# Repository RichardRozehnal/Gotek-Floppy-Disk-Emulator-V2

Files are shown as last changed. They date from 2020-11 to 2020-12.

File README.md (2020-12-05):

# Gotek Floppy Disk Emulator V2

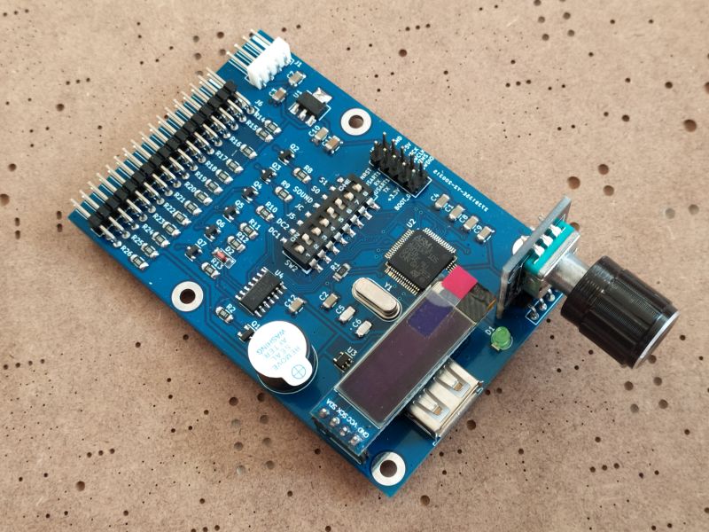
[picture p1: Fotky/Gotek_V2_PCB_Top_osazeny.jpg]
Gotek Floppy Disk Emulator V2


Emulátor disketové mechaniky starých počítačů a různých zařízení. Software se do počítače nahrává z obrazu originálního disku (např. ADF pro Amigu), který je uložen na USB flash disku. Tato verze hardwaru využívá firmware [FlashFloppy](https://github.com/keirf/FlashFloppy/wiki), který přidává spoustu nových funkcí a vylepšení oproti standardnímu Goteku. Na uvedém odkazu tvůrce, najdete detailní popisy všech funkcí a nastavení a také nejnovější firmware.

## Seznam součástek

| **Ref** | **Qnty** | **Value** | **Cmp name** |
| --- | :---: | --- | --- |
| BZ1, | 1 | 5V Active Buzzer 12mm | Buzzer |
| C1, C2, C4, C7, C8, C9, C10, C12, | 8 | 100nF | C |
| C3, C11, | 2 | 10uF | C |
| C5, C6, | 2 | 22pF | C |
| C13, | 1 | 4.7uF/16V | CP |
| D1, | 1 | LED Green | LED |
| D2, | 1 | 1N4148 | D |
| J1, | 1 | Power Connector | Conn\_01x04 |
| J2, | 1 | OLED Display 0.91" Module | OLED\_Display\_0.91"\_Module |
| J3, | 1 | USB\_A | USB\_A |
| J5, | 1 | Programming Connector | Conn\_02x05\_Odd\_Even |
| J6, | 1 | Floppy Data Connector | Conn\_02x17\_Odd\_Even |
| Q1, | 1 | MMBT2222 | Q\_NPN\_BEC |
| Q2, Q3, Q4, Q5, Q6, Q7, | 6 | BSS123 | BSS123 |
| R1, | 1 | 4K7 | R |
| R2, R3, R7, R8, R9, R10, R11, R12, R13, R14, R15, R16, R17, R18, R19, R20, R21, R22, R23, R24, R25, R26, | 22 | 1K | R |
| R4, R27 | 2 | 10K | R |
| R5, R6, | 2 | 22R | R |
| SW1, | 1 | KY040 Rotary Encoder Module | KY040\_Rotary\_Encoder\_Module |
| SW2, | 1 | DIP Switch | DIP\_Switch |
| U1, | 1 | AMS1117-3.3 | AMS1117-3.3 |
| U2, | 1 | STM32F105RBTx | STM32F105RBTx |
| U3, | 1 | STMPS2141 | STMPS2141 |
| U4, | 1 | 74HCT04 | 74HCT04 |
| Y1, | 1 | 8MHz | Crystal |

## Oživení

### Programování mikrokontroléru pomocí ST-Link V2

1. stáhněte si a nainstalujte flashovací program STM32-ST-Link Utility na webu [st.com](https://www.st.com/en/development-tools/stsw-link004.html).
2. propojte ST-Link V2 a Gotek V2 vývody SWCLK, SWDIO, GND a +3.3V
3. připojte ST-Link V2 k PC a spusťte flashovací program
4. připojte se na MCU přes menu Target/Connect
5. přes menu File/Open File vyberte soubor FF_Gotek-v3.20.hex (nebo jiný, který chcete nahrát do MCU)
6. spusťte flashování přes menu Target/Program & Verify a Start

### Nastavení DIP přepínače SW2

Pro Amigu, Atari ST a další počítače je nastavení:

| **sig** | **zap/vyp** | **funkce** |
| :-----: | :---: | --- |
| DC1 | OFF | |
| DC2 | ON | |
| J5 | OFF | |
| JC | OFF | |
| JB | ON | zapnutí/vypnutí emulace zvuku mechaniky |
| S0 | ON | |
| S1 | OFF | |

### Příprava USB flash disku a základní operace

1. USB flash disk naformátujte na FAT32 a nahrajte na něj obrazy disků, které budete chtít spouštět, např. ADF pro Amigu
2. připojte Gotek V2 s vloženým USB flash diskem k Amize (místo interního floppy disku), napájecí konektor je dobré před zapojením změřit, abyste do Goteku V2 nepustili 12V místo 5V, kvůli obrácení konektoru!
3. zapněte Amigu, na displeji se zobrazí první z podporovaných souborů, které jste nahráli a rotačním enkodérem mezi nima vybíráte
4. když najedete na soubor a počkáte 2s, tak se automaticky spustí (vloží do floppy mechaniky). Toto je možné v nastavení změnit, aby se automaticky nespouštěl. Potom bude pro vložení do mechaniky nutné stisknout rotační enkodér.
5. pokud chcete změnit orientaci posuvu v souborech (otáčení enkodéru doprava/doleva posouvat soubory nahoru/dolů), je to možné změnit v nastavení.
6. pokud se výběr souborů posune o jednu položku až při dvou nebo čtyřech krocích otočení enkodérem, je možné toto také upravit v nastavení

### Nastavení firmware

1. Gotek V2 funguje s defaultním nastavením i bez konfiguračního souboru
2. pokud však chcete určitou konfiguci změnit, vytvořte na USB flash disku adresář FF a do něj nahrajte konfigurační soubor FF.CFG
3. zrušení automatického spouštění souboru: autoselect-file-secs = 0
4. zrušení automatického vybrání adresáře: autoselect-folder-secs = 0
5. změna orientace posuvu v souborech: rotary = reverse
6. změna kroků enkodéru: rotary = half
7. je možné vybrat i více nastavení najednou, např.: rotary = reverse,half

## Další fotky (vzorky, úprava na BOT straně již není potřeba)

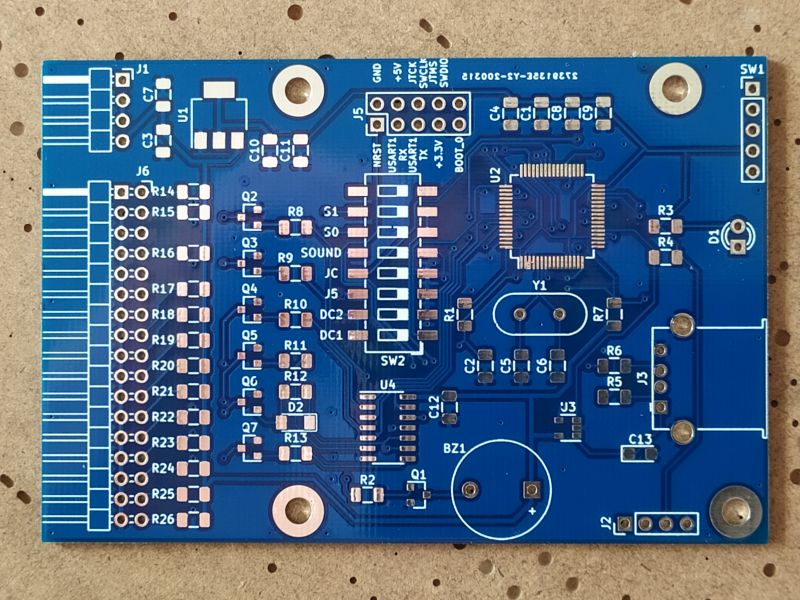
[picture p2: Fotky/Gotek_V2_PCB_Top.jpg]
Gotek_V2_PCB_Top

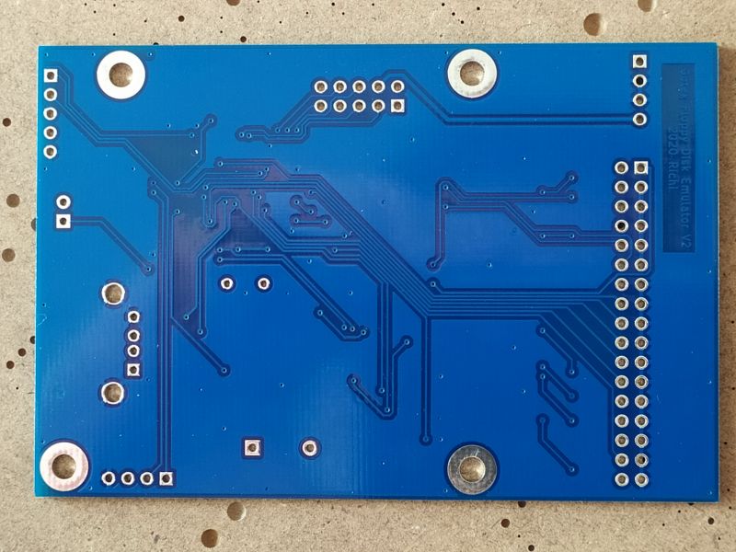
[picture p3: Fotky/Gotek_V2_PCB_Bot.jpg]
Gotek_V2_PCB_Bot

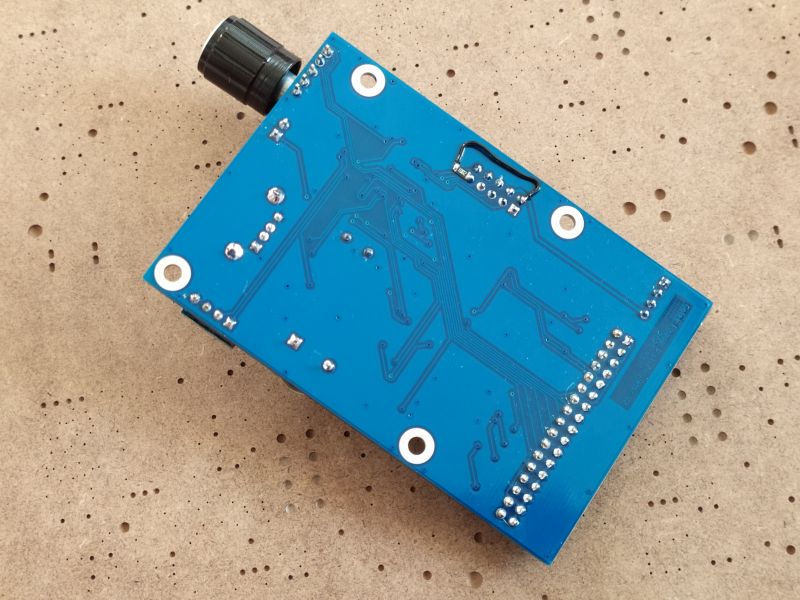
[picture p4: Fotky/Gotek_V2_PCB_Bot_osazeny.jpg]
Gotek_V2_PCB_Bot_osazeny


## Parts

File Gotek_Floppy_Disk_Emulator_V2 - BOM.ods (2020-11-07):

Gotek Floppy Disk Emulator V2 – BOM
Ref | Qnty | Value | Cmp name | Footprint
BZ1, | 1 | 5V Active Buzzer 12mm | Buzzer | Buzzer_12x9.5RM7.6
C1, C2, C4, C7, C8, C9, C10, C12, | 8 | 100nF | C | C_1206_3216Metric
C3, C11, | 2 | 10uF | C | C_1206_3216Metric
C5, C6, | 2 | 22pF | C | C_1206_3216Metric
C13, | 1 | 4.7uF/16V | CP | CP_EIA-3216-18_Kemet-A
D1, | 1 | LED Green | LED | LED_D3.0mm
D2, | 1 | 1N4148 | D | D_MiniMELF
J1, | 1 | Power Connector | Conn_01x04 | PinHeader_1x04_P2.54mm_Horizontal
J2, | 1 | OLED Display 0.91" Module | OLED_Display_0.91"_Module | OLED_Display_0.91_Module
J3, | 1 | USB_A | USB_A | USB_A_Stewart_SS-52100-001_Horizontal
J5, | 1 | Programming Connector | Conn_02x05_Odd_Even | PinHeader_2x05_P2.54mm_Vertical
J6, | 1 | Floppy Data Connector | Conn_02x17_Odd_Even | PinHeader_2x17_P2.54mm_Horizontal
Q1, | 1 | MMBT2222 | Q_NPN_BEC | SOT-23
Q2, Q3, Q4, Q5, Q6, Q7, | 6 | BSS123 | BSS123 | SOT-23
R1, | 1 | 4K7 | R | R_1206_3216Metric
R2, R3, R7, R8, R9, R10, R11, R12, R13, R14, R15, R16, R17, R18, R19, R20, R21, R22, R23, R24, R25, R26, | 22 | 1K | R | R_1206_3216Metric
R4, R27 | 2 | 10K | R | R_1206_3216Metric
R5, R6, | 2 | 22R | R | R_1206_3216Metric
SW1, | 1 | KY040 Rotary Encoder Module | KY040_Rotary_Encoder_Module | PinHeader_1x05_P2.54mm_Vertical
SW2, | 1 | DIP Switch | DIP_Switch | SW_DIP_SPSTx08_Slide_6.7x21.88mm_W8.61mm_P2.54mm_LowProfile
U1, | 1 | AMS1117-3.3 | AMS1117-3.3 | SOT-223-3_TabPin2
U2, | 1 | STM32F105RBTx | STM32F105RBTx | LQFP-64_10x10mm_P0.5mm
U3, | 1 | STMPS2141 | STMPS2141 | SOT-23-5
U4, | 1 | 74HCT04 | 74HCT04 | SOIC-14_3.9x8.7mm_P1.27mm
Y1, | 1 | 8MHz | Crystal | Crystal_HC49-4H_Vertical

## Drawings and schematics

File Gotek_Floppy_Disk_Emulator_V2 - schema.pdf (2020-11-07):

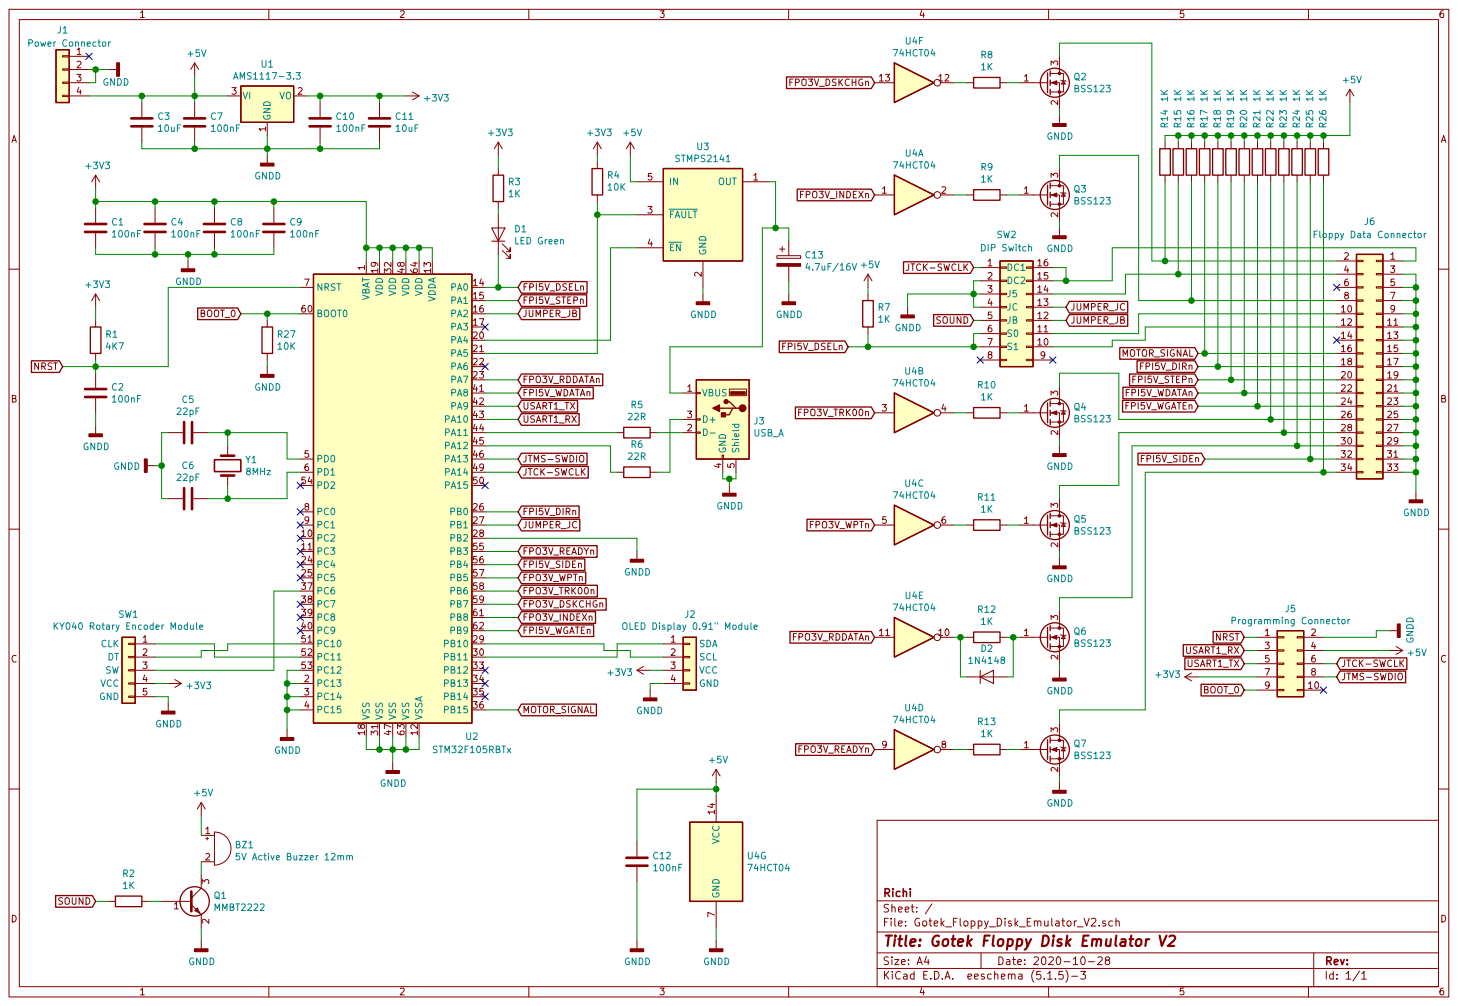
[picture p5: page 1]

1 PC2 10 PC3 11 VSSA 12 VDDA 13 PA0 14 PA1 15 PA2 16 PA3 17 VSS 18 VDD 19 PC13 2 PA4 20 PA5 21 PA6 22 PA7 23 PC4 24 PC5 25 PB0 26 PB1 27 PB2 28 PB10 29 PC14 3 PB11 30 VSS 31 VDD 32 PB12 33 PB13 34 PB14 35 PB15 36 PC6 37 PC7 38 PC8 39 PC15 4 PC9 40 PA8 41 PA9 42 PA10 43 PA11 44 PA12 45 PA13 46 VSS 47 VDD 48 PA14 49 PD0 5 PA15 50 PC10 51 PC11 52 PC12 53 PD2 54 PB3 55 PB4 56 PB5 57 PB6 58 PB7 59 PD1 6 BOOT0 60 PB8 61 PB9 62 VSS 63 VDD 64 NRST 7 PC0 8 PC1 9 U2 STM32F105RBTx GNDD
+3V3 GNDD GNDD

10 | | 9
12 | | 11
14 | | 13

18 | 17
20 | 19
22 | 21
24 | 23
26 | 25
28 | 27
30 | 29

Id: 1/1 Title: Gotek Floppy Disk Emulator V2

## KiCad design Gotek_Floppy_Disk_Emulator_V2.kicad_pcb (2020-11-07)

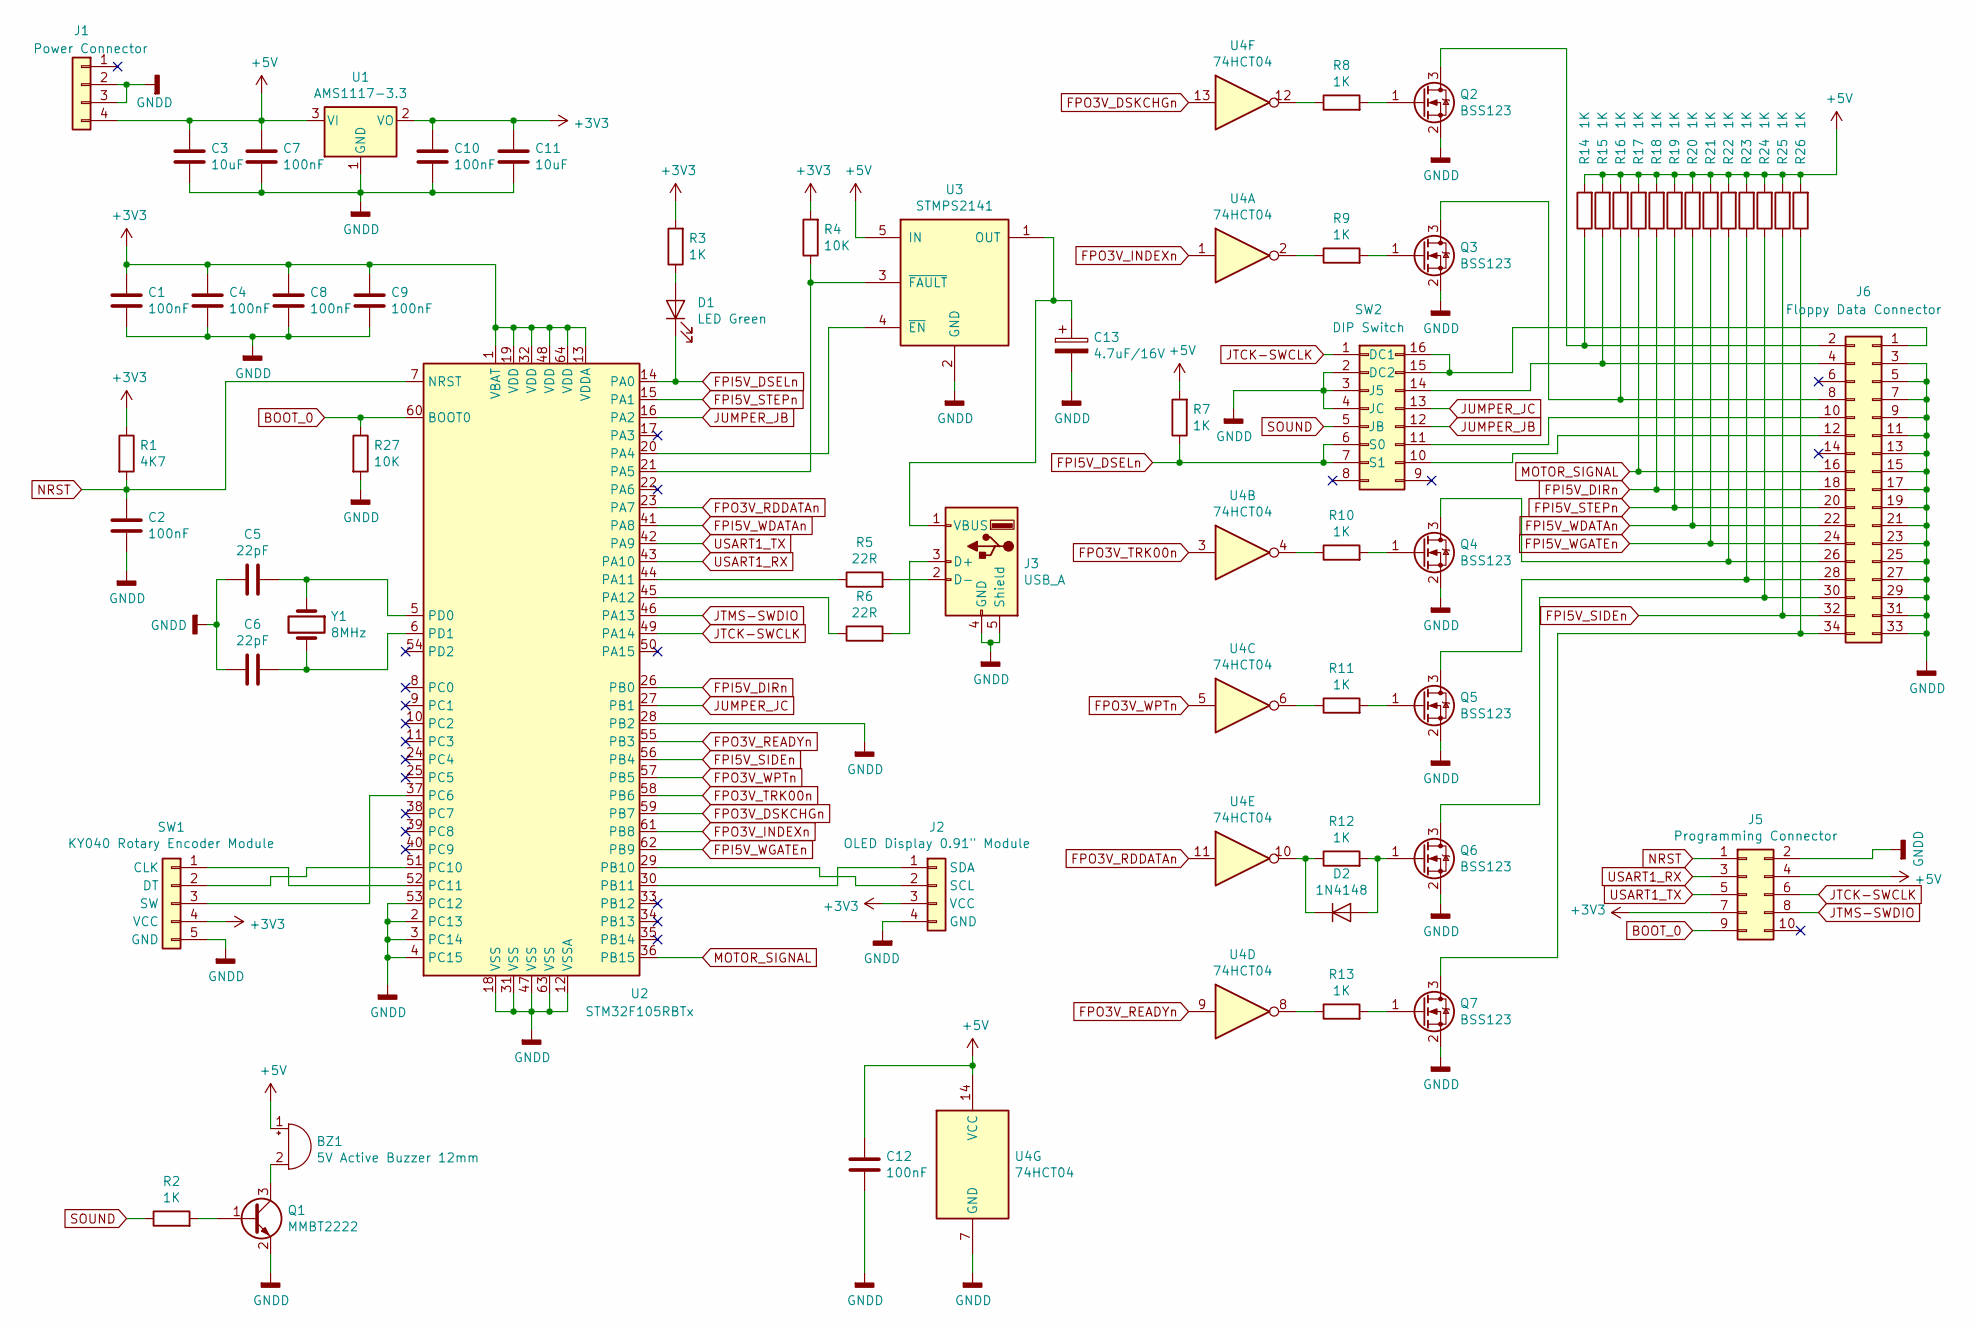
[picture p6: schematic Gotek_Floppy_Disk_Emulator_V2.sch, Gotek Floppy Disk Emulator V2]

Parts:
BZ1: 5V Active Buzzer 12mm; Buzzer_12x9.5RM7.6
C1, C2, C4, C7, C8, C9, C10, C12: 100nF; C_1206_3216Metric
C3, C11: 10uF; C_1206_3216Metric
C5, C6: 22pF; C_1206_3216Metric
C13: 4.7uF/16V; CP_EIA-3216-18_Kemet-A
D1: LED Green; LED_D3.0mm
D2: 1N4148; D_MiniMELF
J1: Power Connector; PinHeader_1x04_P2.54mm_Horizontal
J2: OLED Display 0.91\" Module; OLED_Display_0.91_Module
J3: USB_A; USB_A_Stewart_SS-52100-001_Horizontal
J5: Programming Connector; PinHeader_2x05_P2.54mm_Vertical
J6: Floppy Data Connector; PinHeader_2x17_P2.54mm_Horizontal
Q1: MMBT2222; SOT-23
Q2, Q3, Q4, Q5, Q6, Q7: BSS123; SOT-23
R1: 4K7; R_1206_3216Metric
R2, R3, R7, R8, R9, R10, R11, R12, R13, R14, R15, R16, R17, R18, R19, R20, R21, R22, R23, R24, R25, R26: 1K; R_1206_3216Metric
R4, R27: 10K; R_1206_3216Metric
R5, R6: 22R; R_1206_3216Metric
SW1: KY040 Rotary Encoder Module; PinHeader_1x05_P2.54mm_Vertical
SW2: DIP Switch; SW_DIP_SPSTx08_Slide_6.7x21.88mm_W8.61mm_P2.54mm_LowProfile
U1: AMS1117-3.3; SOT-223-3_TabPin2
U2: STM32F105RBTx; LQFP-64_10x10mm_P0.5mm
U3: STMPS2141; SOT-23-5
U4: 74HCT04; SOIC-14_3.9x8.7mm_P1.27mm
Y1: 8MHz; Crystal_HC49-4H_Vertical

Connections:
+3V3: C1.1, C4.1, C8.1, C9.1, C10.1, C11.1, J2.3 (VCC), J5.7, R1.1, R3.2, R4.2, SW1.4 (VCC), U1.2 (VO), U2.1 (VBAT), U2.13 (VDDA), U2.19 (VDD), U2.32 (VDD), U2.48 (VDD), U2.64 (VDD)
+5V: BZ1.1 (-), C3.1, C7.1, C12.1, J1.4, J5.4, R7.2, R14.2, R15.2, R16.2, R17.2, R18.2, R19.2, R20.2, R21.2, R22.2, R23.2, R24.2, R25.2, R26.2, U1.3 (VI), U3.5 (IN), U4.14 (VCC)
BOOT_0: J5.9, R27.1, U2.60 (BOOT0)
FPI5V_DIRn: J6.18, R18.1, U2.26 (PB0)
FPI5V_DSELn: D1.1 (K), R7.1, SW2.6 (S0), SW2.7 (S1), U2.14 (PA0)
FPI5V_SIDEn: J6.32, R25.1, U2.56 (PB4)
FPI5V_STEPn: J6.20, R19.1, U2.15 (PA1)
FPI5V_WDATAn: J6.22, R20.1, U2.41 (PA8)
FPI5V_WGATEn: J6.24, R21.1, U2.62 (PB9)
FPO3V_DSKCHGn: U2.59 (PB7), U4.13
FPO3V_INDEXn: U2.61 (PB8), U4.1
FPO3V_RDDATAn: U2.23 (PA7), U4.11
FPO3V_READYn: U2.55 (PB3), U4.9
FPO3V_TRK00n: U2.58 (PB6), U4.3
FPO3V_WPTn: U2.57 (PB5), U4.5
GNDD: C1.2, C2.2, C3.2, C4.2, C5.2, C6.2, C7.2, C8.2, C9.2, C10.2, C11.2, C12.2, C13.2, J1.2, J1.3, J2.4 (GND), J3.4 (GND), J3.5 (Shield), J5.2, J6.3, J6.5, J6.7, J6.9, J6.11, J6.13, J6.15, J6.17, J6.19, J6.21, J6.23, J6.25, J6.27, J6.29, J6.31, J6.33, Q1.2 (E), Q2.2 (S), Q3.2 (S), Q4.2 (S), Q5.2 (S), Q6.2 (S), Q7.2 (S), R27.2, SW1.5 (GND), SW2.2 (DC2), SW2.3 (J5), SW2.4 (JC), U1.1 (GND), U2.2 (PC13), U2.3 (PC14), U2.4 (PC15), U2.12 (VSSA), U2.18 (VSS), U2.28 (PB2), U2.31 (VSS), U2.47 (VSS), U2.53 (PC12), U2.63 (VSS), U3.2 (GND), U4.7 (GND)
JTCK-SWCLK: J5.6, SW2.1 (DC1), U2.49 (PA14)
JTMS-SWDIO: J5.8, U2.46 (PA13)
JUMPER_JB: SW2.12, U2.16 (PA2)
JUMPER_JC: SW2.13, U2.27 (PB1)
MOTOR_SIGNAL: J6.16, R17.1, U2.36 (PB15)
NRST: C2.1, J5.1, R1.2, U2.7 (NRST)
unnamed: BZ1.2 (+), Q1.3 (C)
unnamed: C5.1, U2.5 (PD0), Y1.1
unnamed: C6.1, U2.6 (PD1), Y1.2
unnamed: C13.1, J3.1 (VBUS), U3.1 (OUT)
unnamed: D1.2 (A), R3.1
unnamed: D2.1 (K), R12.1, U4.10
unnamed: D2.2 (A), Q6.1 (G), R12.2
unnamed: J2.1 (SDA), U2.30 (PB11)
unnamed: J2.2 (SCL), U2.29 (PB10)
unnamed: J3.2 (D-), R5.2
unnamed: J3.3 (D+), R6.2
unnamed: J6.1, SW2.15, SW2.16
unnamed: J6.2, Q2.3 (D), R14.1
unnamed: J6.4, R15.1, SW2.14
unnamed: J6.8, Q3.3 (D), R16.1
unnamed: J6.10, SW2.11
unnamed: J6.12, SW2.10
unnamed: J6.26, Q4.3 (D), R22.1
unnamed: J6.28, Q5.3 (D), R23.1
unnamed: J6.30, Q6.3 (D), R24.1
unnamed: J6.34, Q7.3 (D), R26.1
unnamed: Q1.1 (B), R2.2
unnamed: Q2.1 (G), R8.2
unnamed: Q3.1 (G), R9.2
unnamed: Q4.1 (G), R10.2
unnamed: Q5.1 (G), R11.2
unnamed: Q7.1 (G), R13.2
unnamed: R4.1, U2.21 (PA5), U3.3 (~FAULT)
unnamed: R5.1, U2.44 (PA11)
unnamed: R6.1, U2.45 (PA12)
unnamed: R8.1, U4.12
unnamed: R9.1, U4.2
unnamed: R10.1, U4.4
unnamed: R11.1, U4.6
unnamed: R13.1, U4.8
unnamed: SW1.1 (CLK), U2.52 (PC11)
unnamed: SW1.2 (DT), U2.51 (PC10)
unnamed: SW1.3 (SW), U2.37 (PC6)
unnamed: U2.20 (PA4), U3.4 (~EN)
SOUND: R2.1, SW2.5 (JB)
USART1_RX: J5.3, U2.43 (PA10)
USART1_TX: J5.5, U2.42 (PA9)

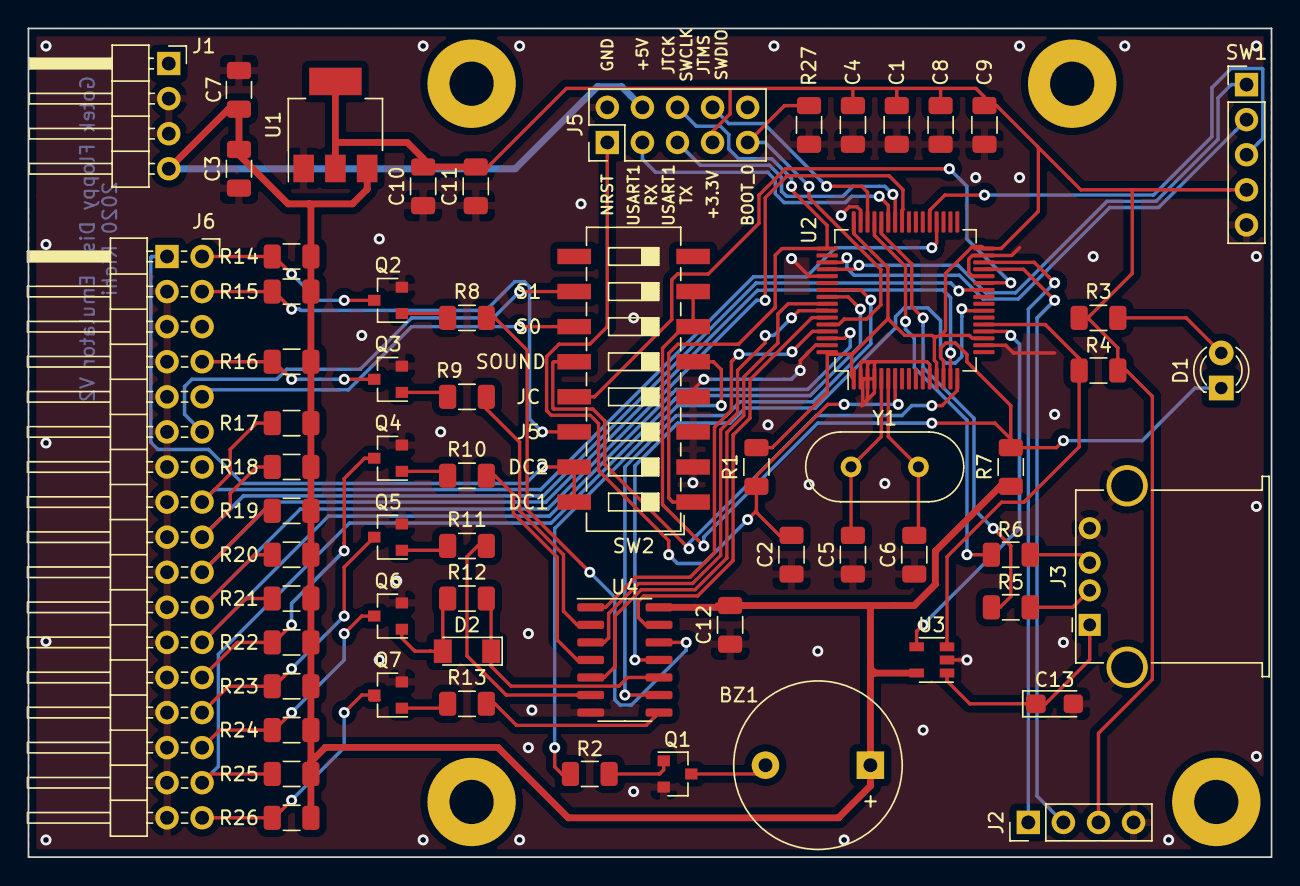
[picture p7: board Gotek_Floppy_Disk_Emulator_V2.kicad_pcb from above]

Board: 2 copper layers, 90.0 x 60.0 mm, 62 parts (0 on the bottom side), 64 nets.

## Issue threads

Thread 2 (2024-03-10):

Confusion about switches DC1 and DC2 ?

zwrr, 2024-03-10:
Hello sir, thank you for creating this project, I am planning to build it for my 386 retro PC, I have a question that I hope you can answer, that is about the switches, I am confused about the role of DC1 and DC2, Hope you can help me, thank you.

RichardRozehnal, 2024-03-11:
Hello,
vintage floppy drives use pin1 of the floppy connector for disk change signal. If you have such a drive you have to connect this pin 1 to PA14 (JTCK-SWCLK) of he MCU, so you have to set DC1 ON and DC2 OFF. If you have newer drive you have to set DC1 OFF and DC2 ON.

Closed 2024-03-16.

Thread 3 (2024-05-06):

jumpers MSX

ralampa, 2024-05-06:
Hello, I have a question, how do they have to put the jumpers to use it on MSX?

RichardRozehnal, 2024-05-07:
Hi,
have you already tried any settings? Try DC1 OFF and DC2 ON. If it doesn't work, try DC1 ON and DC2 OFF. Unfortunatelly I don't know MSX system. :( Or look at original FlashFloppy page, maybe they have some info about MSX system settings.

ralampa, 2024-05-07:
Thank you very much for answering, I already have it solved. I leave here the configuration that has worked for me, in case someone needs S1 ON, S2 OFF, JC OFF, J5 OFF, DC2 ON, DC1 OFF.
Thanks and regards.

Closed 2024-05-07.
